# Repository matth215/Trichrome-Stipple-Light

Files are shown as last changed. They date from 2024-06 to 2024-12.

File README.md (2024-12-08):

# Trichrome-Stipple-Light
Here find my project files for the Stipple Light project I developed as a workshop with Stanford's Lab64 Makerspace. Here you can find build files, instructions, STL models, and arduino code.
The instructions for this project were made with Lab64 in mind, so if you found these instructions online somewhere, they may not be comprehensive enough to serve as "step-by-step" instuctions. Experience with laser cutting, coding, soldering, 3D printing, and general making is highly recommended. Your results may vary depending on the laser cutter you use, for example.   

## Directory of Files
- (start here) **TSL Preprocessing Guide** describes how to turn your image into a cut file for a laser cutter. This is typically the first step to transform your image!
- **TSL Assembly Guide** shows you how to put everything together, including 3D printing, cutting out your images, and assembling the electronics
- **StippleMount** STL 3D file ready for making. Print upside down!
- **StippLED Code** This is arduino code that runs on your Metromini V2. You'll see code versions 2 and 3, although version 3 is cooler.  
- **Trichrome Trotec Template** This is an SVG file for using with the Preprocessing Guide. (Trotec was the brand of the laser cutter we used)
- **Backing** Another SVG file for cutting out the acrylic lid for your stipple mount. This is designed for 1/8" clear acrylic.

## Who to contact
- Me, probably

## Disclaimer
- Because this project was developed as a student project at Stanford University, please reach out if you have any questions on intellectual property or distribution. That being said, this project is totally open source so feel free to make one yourself. 

Example

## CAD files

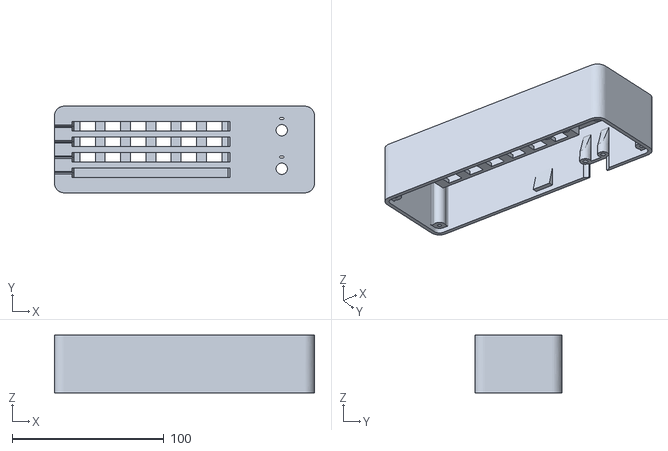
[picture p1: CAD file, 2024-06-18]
StippleMount_V4 (2).stl
171.4 x 57.2 x 38.1

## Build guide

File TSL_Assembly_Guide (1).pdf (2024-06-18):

Trichrome Stipple Light (TSL)
Assembly Guide
Matthew Hamilton for Lab64

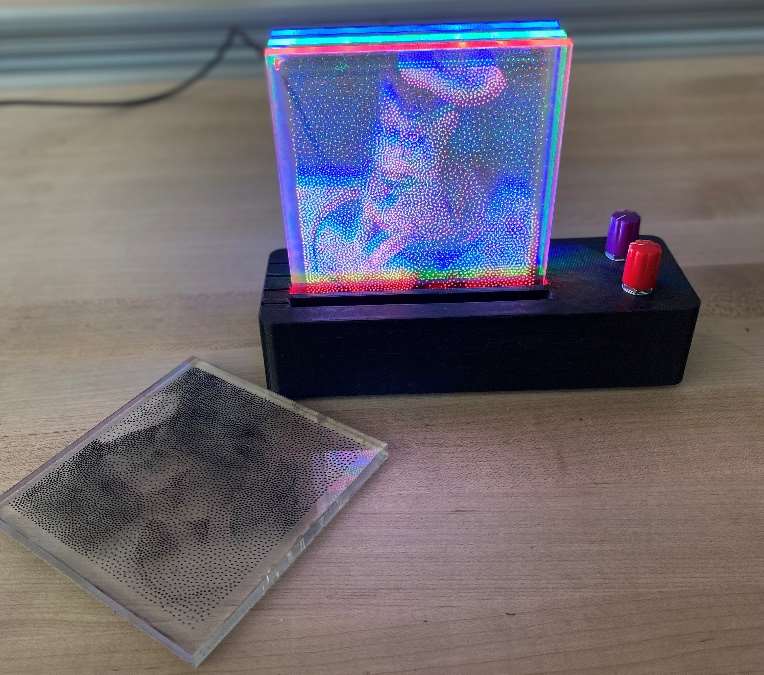
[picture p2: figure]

1

Part 0 - Orienting Yourself
The day of the workshop focuses on integration – basically putting everything together to make the final product. It’s also about sharing skills! Here you will be soldering the guts of the stipple holder, assembling the potentiometers, and putting everything into the enclosure for a clean package. All the while, your SVG files will be laser-cut out of acrylic and will be ready during the workshop.
If you’re doing this project outside of a workshop, these directions will guide you through soldering your connections, laser cutting your acrylic squares, and assembling the final product.
However, these directions don’t function as an introduction to soldering, 3D printing, or laser cutting! That’s where skill sharing comes in – if you need help along the way, reach out to a Lab64 Course Assistant to aid you in any of the techniques discussed here. You should also talk to anyone else that’s working on this project. Experience is a great teacher and they’ll be able to pass on tips and tricks not covered in this document.

Figure 1: Completed TSL prototype with Black Channel Removed
You can follow these directions sequentially, but can also choose to start at Part 1, Part 2, or Part 4. You’ll eventually hit every part on the way to completing this project.

Part 1 - Print your Stipple Holder
3D printing usually takes several hours, so it’s a good idea to start this step early. You can solder and assemble the electronics portion ahead of time while your holder is being printed. Download the Stipple Holder on the Lab64 GitLab site and import it into the Prusa Slicer.

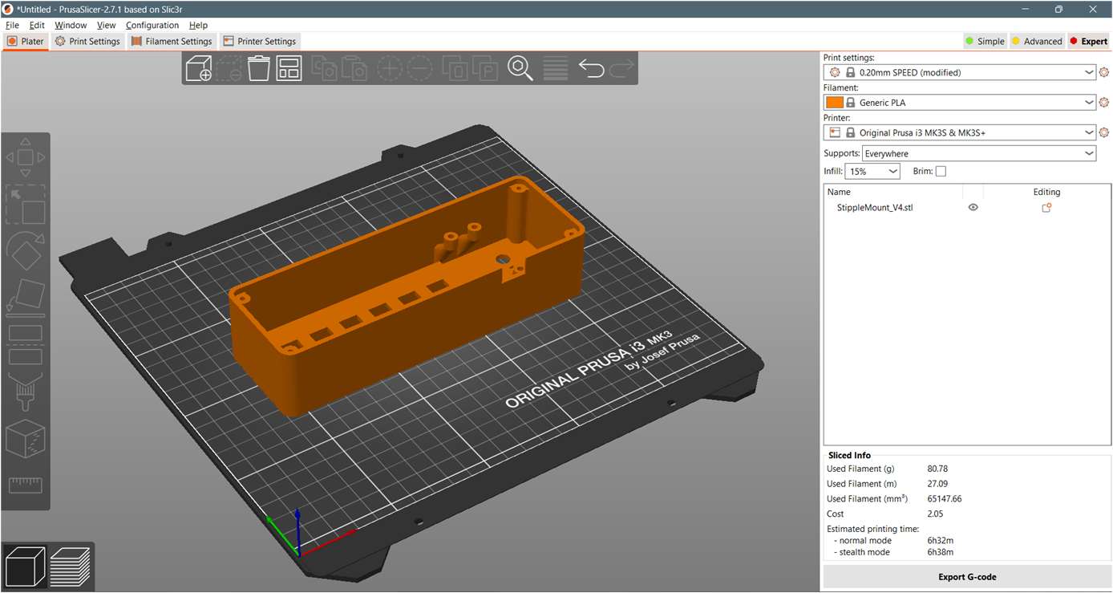
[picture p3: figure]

2

Figure 2: PrusaSlicer for the Stipple Holder
You’ll want to print it upside-down to minimize wasteful supports inside the cavity. Keep the infill to 15% with supports everywhere. Make sure “Brim” is NOT selected, or you’ll have a hard time removing supports and cleaning the edges of the box. You can use any detail and layer height that works for you. The screenshot above is just a recommendation.
Assuming your bed has no temperature issues, bed adhesion should not be a problem. In testing, we observed it takes between 8 and 11 hours to print a holder. As always, you can find the 3D model, directions, and code on our website at https://lab64.stanford.edu/.

### 1.1 Adding Heatset Inserts

You might have noticed that the underside of the Stipple Holder has 4 mounting holes in a rectangular pattern. These are sized for M2 4mm “Heatset Inserts” which couple with M2 screws and solidly secure the microcontroller to the holder. Since this is where you’ll plug and unplug your completed TSL, a mechanically sti mounting point is critical!
If you’ve never used a Heatset insert before, you’re in for a treat. They’re both an elegant way to mount components onto a 3D print (or another thermoplastic) and are immensely satisfying to use. You’ll need a hot soldering iron, your 4 brass inserts, and a pair of tweezers. With your holder upside-down on a workbench, heat up your soldering iron. Position one insert so that the wider diameter is facing up. Use your tweezers to move the insert to one of the mounting holes in your stipple holder.
Next, make sure the soldering iron tip is completely clean and free of solder. Touch the tip of the soldering iron to the brass insert to heat it up. At the same time, use your tweezers to guide the insert into the mounting holes until the brass insert reaches the bottom, and the top of the insert is flush with the sides of the mounts. CAREFULLY reposition your tweezers to the top of the insert so that they’re right next to the soldering iron tip. Remove the soldering iron tip and use the tweezers to keep the insert in place. This part is critical so that you don’t rip out the brass insert on accident!

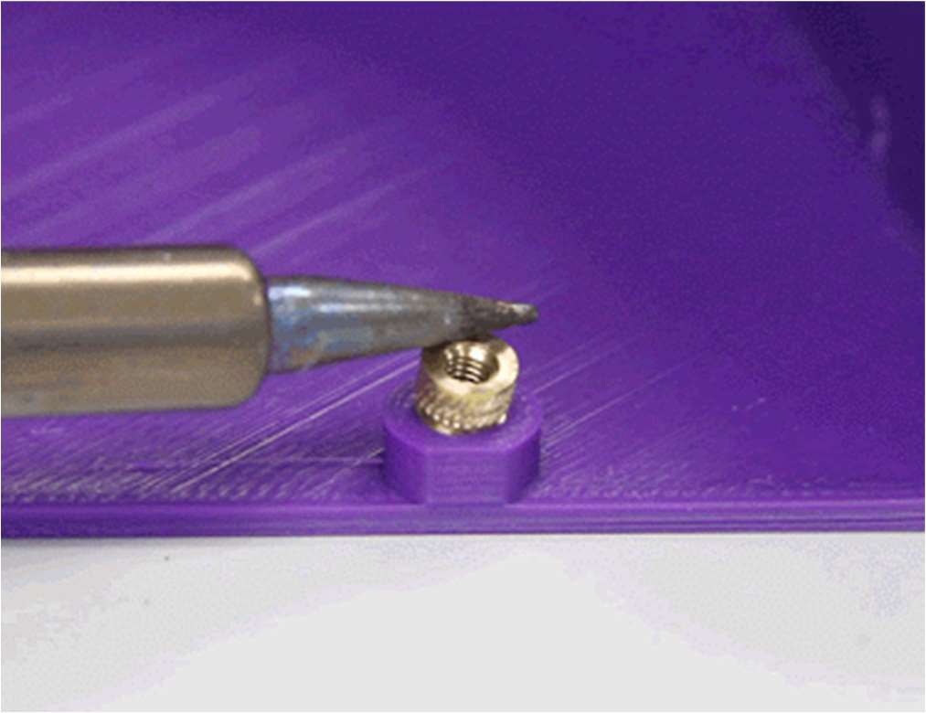
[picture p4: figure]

3

Figure 3: Animation of heatset insert process

Part 2 – Soldering
Soldering the connections for this project takes the most time out of the steps listed here. If you’re not an experienced solderer (and even if you are) you might find some diiculty soldering the wire and LED strip together. This is because the LED strips are thin and metallic making them excellent heat conductors and heatsinks. This isn’t great for soldering since we need to heat up the surface to ensure a good joint. Before starting o, here are some quick tips to think about before starting. We’ll discuss them in detail in the following directions.
- Tin your tip! Tin your pads! Tin your wires! – Solder bonds to solder easier than to metal
- Heatshrink tubing is critical for ensuring a good mechanical connection
- Use clamps and holders to make soldering wires together easier
- Don’t burn your fingers – yes, it can happen to you!
- Solder the backside of the LED strips
- Daisy-chain your connections
The wiring illustration in the last page of this document will orient you though the assembly. The TSL uses an Adafruit Metro Mini V2 as the microcontroller for this project. It uses the excellent
atmega32 chip commonly found in Arduino microcontrollers. Since it uses 5 volts, it easily powers LED strips without issue and has more than enough analog inputs for our purposes. (It also means you can expand the TSL with many more functions if you want to.)
The illustration shows the red Vdd wires and black Ground wires “daisy chained” together, except in a few spots. This means that instead of every device being wired back individually to the same ground or Vdd pin creating a clumsy ball of wire and solder, these wires jump from one device to another to complete the connections.

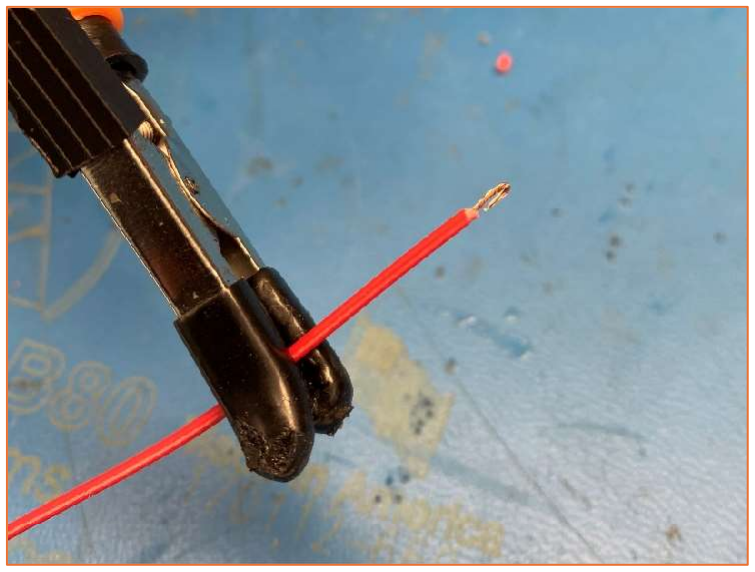
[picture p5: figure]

4

### 2.1 Tinning the Wires

Start by cutting your wires to length and stripping the tips. You’ll need enough wire to connect 2 potentiometers and 3 LED strips. You can do this all at once or as you go, but it helps to cut them ahead of time so that you can tin your wires eiciently. Consider the length of your stipple holder and give yourself some slack so the wires are not stretched when you assemble them later.

Figure 4: One wire ready for tinning, you’ll want to do multiple at a time.

Next, tin all of your wires. Tinning means using your soldering iron to apply solder to the bare wire threads without connecting them to anything. This serves 2 purposes. First, it helps keep your wire strands together. Second, it makes it MUCH easier to bond them to other components. Liquid solder bonds more easily with solder than it does to cold metal like your wire or solder pad. This is an important trick, and it will make assembly easier and less frustrating.
It’s more eicient to do this with several wires all clamped at the same time, rather than individually. Use a table vise or wire grips at your station to clasp several wire ends, but don’t let them touch each other. Apply a small amount of solder to the length of stripped wire to tin them. Then, do the same with the other ends of the wires. This may seem tedious, but it will save you time in the next steps. Don’t be tempted to hold the wires with your fingers! Copper conducts heat quickly and will easily burn you! Use a clamp or vise grip; it’s safer that way.

### 2.2 LED Strips

With the wires tinned, turn your attention to the LED Strip pads. You’ll tin these too, but this can be tricky. Clasp the LED strips in your vise grip and use a little flux to clean the copper pads. Make sure you tin the back side of the pads! Otherwise, the LED Strips won’t lay flat into the stipple mounting holes. All wires going in and out of the LED strips should attach to the back side of the strip, including your signal wires. It’s super important that these connections are snug with the pad and no extra length of wire is exposed. This is a common point of failure – make sure there’s no chance

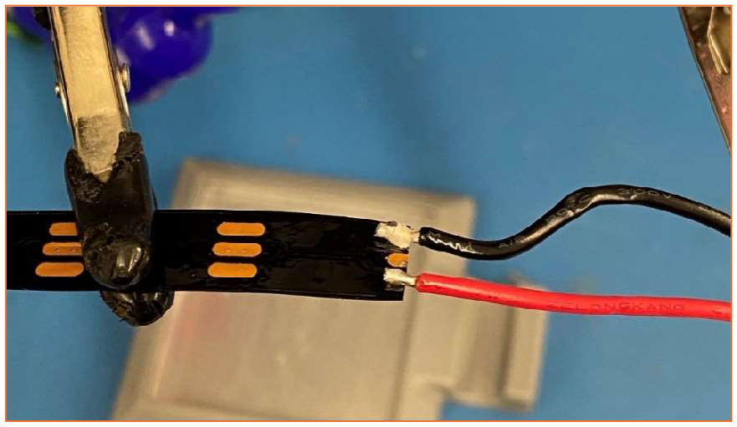
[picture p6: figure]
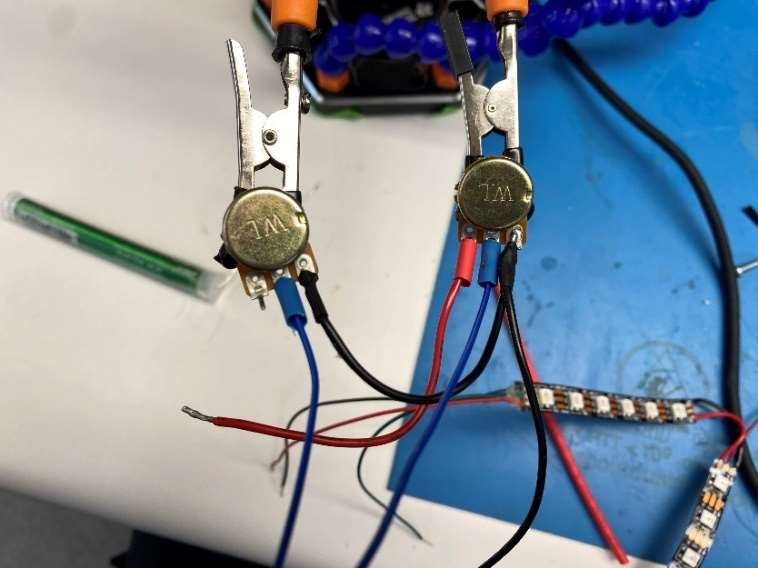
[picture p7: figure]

5

that any of the wires can touch each other! You’ll stabilize this connection later during assembly with hot glue.

Figure 5: Power wires soldered to the LED strips. Note that these are on the back, and the wires insulation is snug with the solder pad

### 2.3 Soldering the Potentiometers

Now you can solder the wires to the potentiometers. Tinning the potentiometer leads can help here too. During the workshop, we noticed that some of the potentiometers are either defective or break during soldering. Try not to apply too much heat to the pot leads when soldering them to reduce this risk. Reference the wiring diagram on the last page and take care to slip on heat shrink tubing on your wires before you solder if you’re soldering multiple wires. Forgetting to put on heat shrink tubing after you’ve made your solder joint is a rite of passage. Since you are daisy chaining the connections, there will be a few points where you’ll slip heatshrink over 2 wires instead of just one!

Figure 6: Wires going to the potentiometers. The “signal” wires are blue.

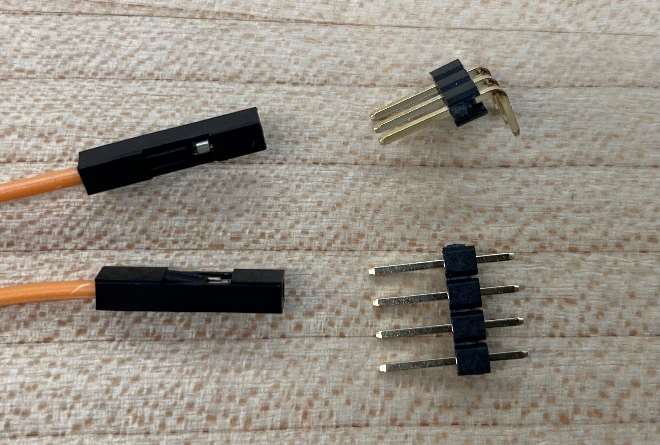
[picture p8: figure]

6

### 2.4 Header Pins

Last but not least, you’ll need to add female header pin connectors to the ends of your signal wires going to the microcontroller. These will connect to the male header pins soldered onto the microcontroller and simplify assembly at the end. (On the wiring diagram, these are the little black rectangles pointing towards the microcontroller.) Secure this splice with a bit of heatshrink.

Figure 7: Female wire header connectors (left) with male header pins in straight and angled variety (right)
Turning to your micro controller, solder the male header pins to your board at the appropriate spots. The angled pins will connect to the LED signal outputs, and the straight ones will connect to power and analog inputs. This is an important detail for assembly later. Just solder the pins you need; don’t use the whole strip or the micro won’t fit into the stipple holder!

### 2.5 Final Steps and Checks

As you work through the solder connections, pay careful attention to the connections, and take your time. When you’re finished, take a look at all of your solder joints to make sure they’re mechanically stable. Could you add heat shrink anywhere? Is there any chance your wires could cross and short out? Are you sure you wired the ground pins to the ground wire, and the power wire to the power pins? Did you connect the LED strip signal wires to the Din side, and are your Dout pads unconnected? Have you had a snack? These soldering steps can take a good amount of time so keep your blood sugar up and don’t get frustrated. If you’re satisfied with your job, congratulations! This is a challenging soldering job that takes a good amount of skill. The next step is testing it with your microcontroller.

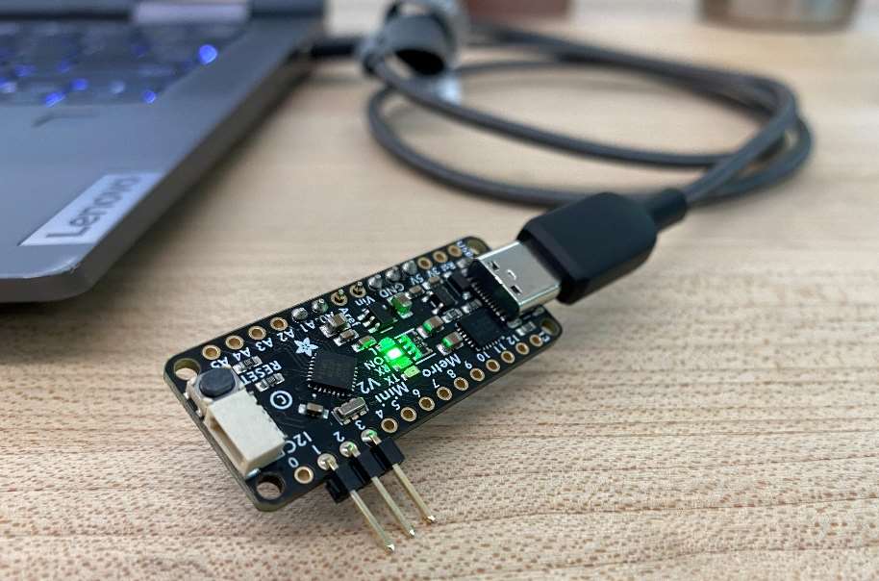
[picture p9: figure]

7

Part 3 - Testing your Circuit and Microcontroller
At this point, your LED strips, potentiometers, and microcontrollers should all be connected together but unattached to the stipple holder. This is a good chance to make sure the guts of this project work right so you can fix issues now. Grab your laptop, microcontroller, and a USB-C connector. You’ll also need the following software:
- Adafruit MCU Drivers, to get the configuration of your MetroMini V2
- Arduino IDE, the development environment for Arduino-based microcontrollers.
- USB to Serial Drivers for connecting to your microcontroller on Windows (if you’re using mac, refer to Adafruit’s guide here
- StippLED Code from Lab64’s Gitlab.

The software above is everything you need for testing, connecting to your microcontroller, and uploading the TSL code. If you have issues with this step, follow the manufacturer's instructions on their website at learn.adafruit.com. Start by downloading and installing all the software listed above.

### 3.1 Connecting to the MCU

With the Arduino IDE page open, connect your computer to the microcontroller using a USB-C cable. Remember, don’t connect any of the electronics in the previous step to your board!

Figure 8: MetroMini V2 connected to a PC. Note there's no other electronic attached to this yet!
If you haven’t already, add the MetroMini v2 to your board manager in the Arduino IDE settings. Reference the screenshot below to connect to your board, but keep in mind that your serial port number will be dierent. It’s typically a number higher than 6. For me, it was COM23 Serial Port (USB). Notably, the serial port number changes every time you reconnect your metro so you may have set the com port again if you disconnect the microcontroller. With your board connected, you can now download the StippLED code and copy it into your board’s .ino file. You’ll also need to install the “fastLED” library from the IDE’s Library Manager, as well as Arduino AVR Boards from the

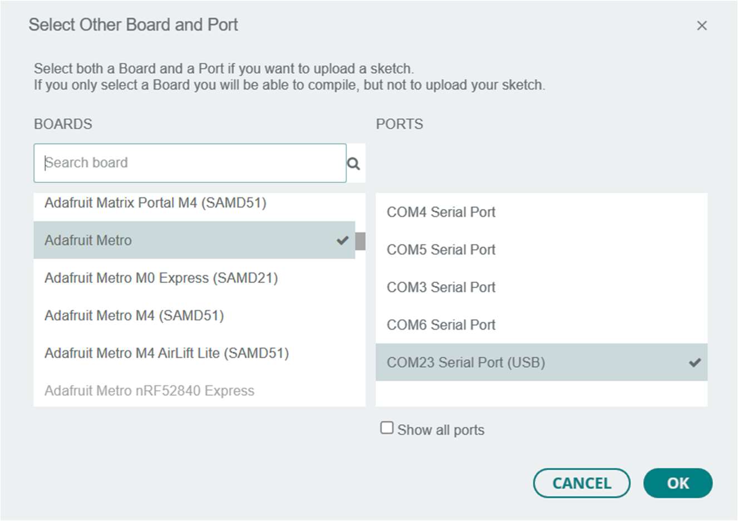
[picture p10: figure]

8

Board Manager. Otherwise, you’ll get an exit error message from the serial terminal whenever you try to upload.

Figure 9: Arduino IDE Boards Manager (under Tools > Board > Boards Manager)
It’s important not to look at the code for too long – it’s probably not up to any CS Major’s standards (from Stanford or anywhere else). This is, however, the best code you can expect from an EE Major who learned Arduino in a few weeks. If you’re comfortable with Arduino this project is an excellent opportunity to develop your own firmware with custom LED animations (once you’ve assembled everything). You’re encouraged to add your own code and share it with everyone else, so that they too can judge your code :)
Now, upload the code using the arrow button. If your code uploaded successfully without error, then your IDE is configured correctly. If not, you might have issues with the board manager, libraries, serial drivers, or MCU drivers. Go back and check these before proceeding to the next step.

### 3.2 Testing the Electronics

Bring over your mess of LED strips and wires to your microcontroller. Unplug your microcontroller from your computer so that it’s completely powered o. While looking at the schematic diagram, connect the female header sockets to the male header pins on your microcontroller. Take special care in ensuring that you’re not shorting any connections accidently. Then reconnect the microcontroller to your computer. The micro should immediately begin illuminating the LEDs depending on the position of the potentiometers. Turn both POTs and see if it’s working as expected. One POT will shift through color schemes, and the other will vary the intensity of the lights.

9

### 3.3 Troubleshooting

If your lights are not working as expected but you uploaded code in the last step, the issue is with your circuit. A short in your wiring can cause issues compiling code to your microcontroller! This is why we tried uploading the code to the micro before testing the circuitry. Here are common issues we found during the workshop.

### 1. LED strips are flashing and/or sensitive to small adjustments: Check the wiring at the

LED strip pads and make sure there are no shorts. Are your wires soldered closely to the pads like in figure 4?
2. Some strips are not illuminating: Check that your signal wires are connected to the Dn (or Din) pads, and the Do (Dout) pads are not connected.

### 3. Turning the POTs does nothing: You might have a bad potentiometer causing an open or

short condition inside the canister. Test the resistance value using a multimeter. Also check that the signals inputs are connected to AD1 and AD2.
4. Trying to upload the code fails and nothing works: You likely have a short between 5v and ground pins somewhere in your wiring resulting in insuicient power to run your microcontroller. Trace these connections and find the fault.

### 5. Code uploaded successfully, but nothing works: Check the power and ground

connections and ensure they are soldered properly. It’s also possible that your POT inputs and signal outputs are shorted to ground or 5v preventing a signal from reaching your LED strips.
Once you’ve worked out all of the bugs in your circuit and it works as expected, you can move on to another part.

Part 4 – Acrylic Laser Cutting and Finishes
You’ll need laser cutter training to do this part alone or ask a CA for help. We used the following settings to cut the acrylic from the templates.
Engraving: Power: 80, Speed: 30, dpi: 333 to 500
Cutting: Power 70, Speed: 0.55, passes: 2
Cutting 4 acrylic squares at the same time can take around 30 minutes as the laser head rasters over the sheet. After they’re done, you can start putting the finishing touches on the 4 color channels. They’ll still be dusty from the cut, so the first step is to wash them vigorously in the sink.

### 4.1 Preparing and Painting

Take them over to the reflow room and use the lab sink to wash out the acrylic dust. The dust tends to get stuck in the stipple dots, so wash them until the acrylic appears clear under the water. You can also remove the plastic film from the blanks at this point. Dry them o using a microfiber towel. Acrylic can scratch easily, so be careful and don’t use any hard tools! If you’re a perfectionist, you can look at the stipples under the microscope in our lab.

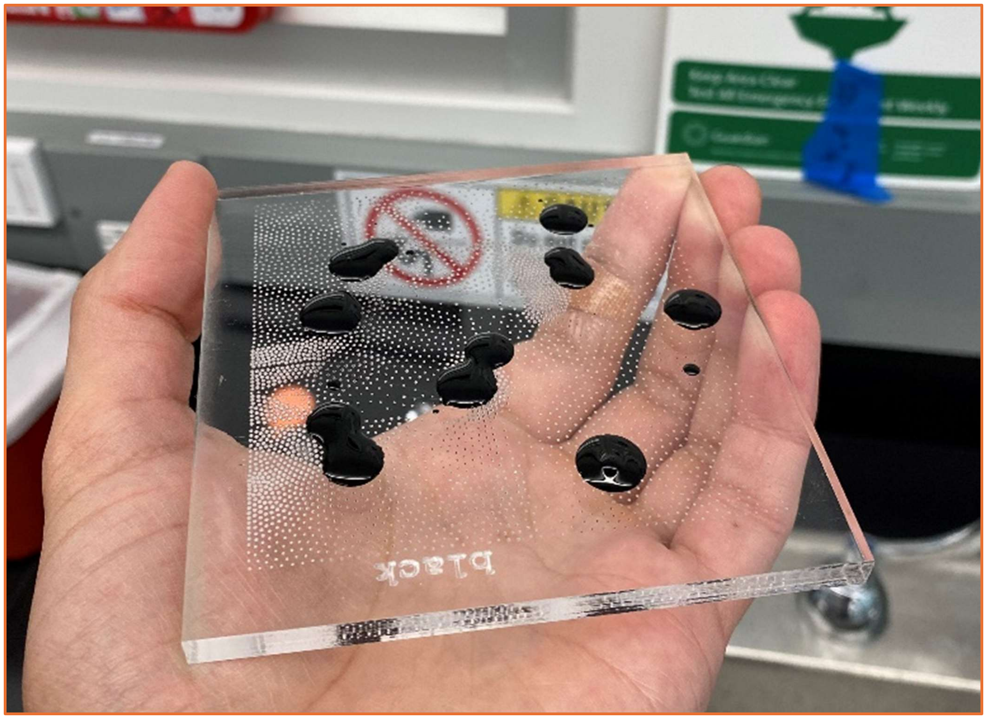
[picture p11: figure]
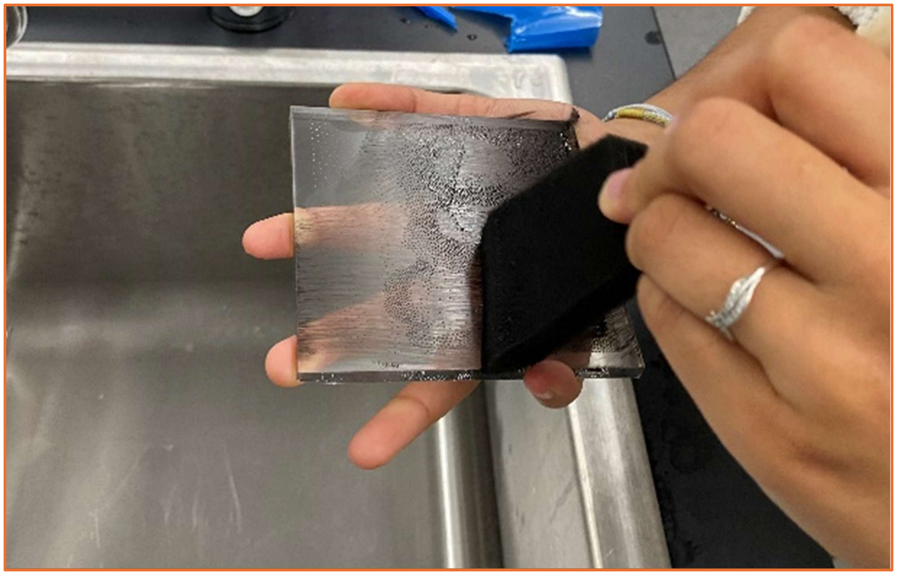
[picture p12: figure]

10

Now find your black acrylic square. If you labeled it, this should be easy. If not, then you’ll notice that one of the images has a notably dierent pattern than the color channels and you can hopefully find it this way. In this step, we’re going to add pigment to the stipples so that they blend and add darkness in the resulting image. This isn’t possible with RGB light alone, after all. Remember – we’re only doing this with the black channel! Not the other color channels!
Over the sink (please), use the tube of black acrylic paint and add several drops to the stippled surface of your plate like this:

Figure 10: Black paint on the black channel
Then using the paint brushes, dab the black paint into all the little stipples. Do this several times to really get the paint in there. It can help to use a paper towel and circular movements to better put the paint into the stipples.

Figure 11: Brushing the black paint on
With enough work, you’ll see the black paint covering the entire square. Then, use a damp paper towel to wipe the excess paint o and clean up the square. Take a look at how the acrylic paint has filled the dots. If you’re not satisfied, repeat this process until you are.

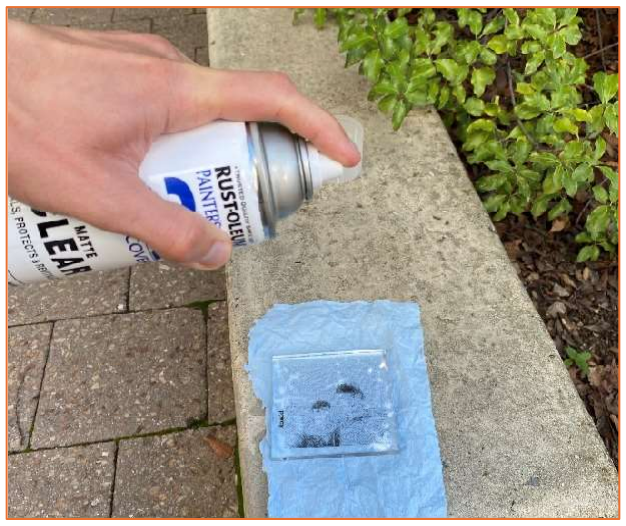
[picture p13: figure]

11

### 4.1 For Overachievers

If you really want to make sure all the stipples are filled you can take the extra step of evacuating the air in the acrylic paint. You can use the small vacuum chamber along with the vacuum pump to pull all of the air out of the paint.
Apply a thick coat of paint on the stipples, then place it in a plastic container that will fit into the vacuum chamber. Place both at the bottom of the chamber then place the lid on top being sure to center it exactly. Pull a vacuum in the chamber until the pressure has stabalized. You’ll see all of the air leave the paint and dry out a little bit. Leave it for about 1 minute, then return pressure to the vessel. Take out the acrylic and wipe o the surface. This is the best way to ensure the paint has entered every single stipple.

### 4.2 Optional Step:

We’re not sure how good this eect looks, but you can add a coat of matte clear coat on the black mask to “enhance the blending eect”. It makes the image look better upclose (maybe), but isn’t necessary to get the full eect. This is an asthetic choice.

Figure 12: Spray lightly from about 1 foot away to apply an even coat

Part 5 - Putting It All Together
You have your clean acrylic squares and they’re ready to go. You’ve tested your spaghetti mess of wires and LED strips with your microcontroller and it all works great. Your Stipple Holder is clean and the heatset inserts have been heated, set, and insterted. It’s time to put it all together.

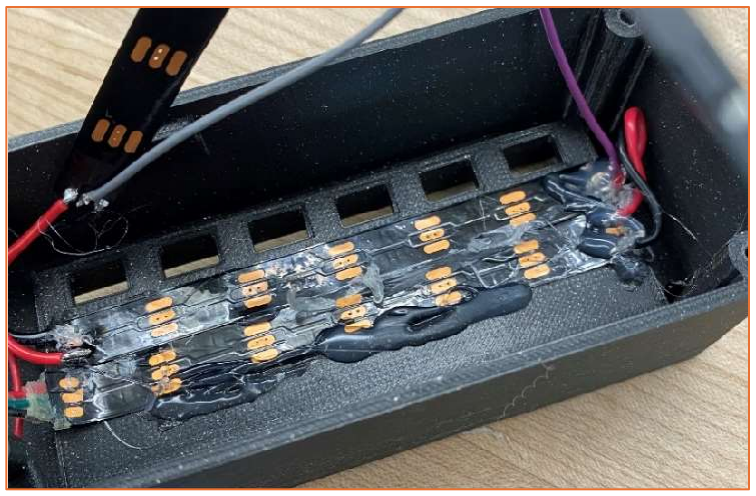
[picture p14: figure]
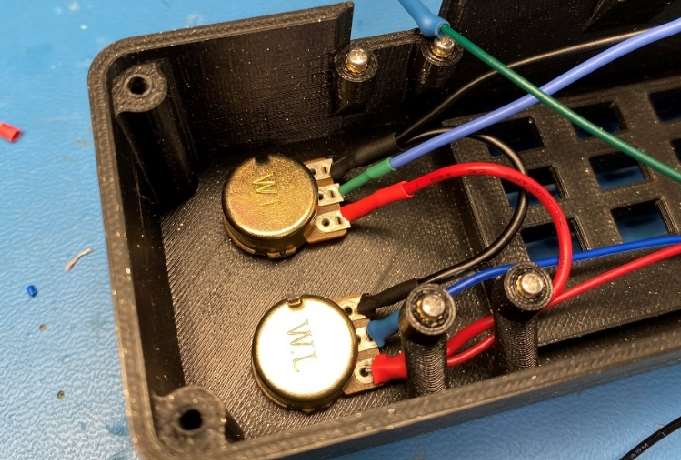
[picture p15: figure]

12

### 5.1 Hot glue for the LED Strips

Begin by carefully test fitting the led strips into the holder. You’ll notice that there’s a gap for every led strip. Here, you’ll use a little hot glue along the edges and “bridges” of the slots to hold your LED strips in place. This can be messy but it works well.

Figure 13: 2 out of 3 hot-glued LED strips. Glue on the solder pads also help prevent shorts during assembly
Next insert your potentiometers. These don’t need hot glue and instead secure with a washer and nut on the top face. When that’s done, add the knobs of your choice to the two pot shafts. These typically secure with pressure alone, or with a small hexscrew on the side of the knob which you’ll adjust with a allen wrench (hex key).

Figure 14: Pots inserted into the stipple holder

### 5.2 Microcontroller and connections

Next, secure your microcontroller to the 4 inserts you secured in part 1 with 4 small 2M screws. Because this microcontroller is also the main plug for your stipple holder, the heat set inserts provide a mechanically stable and secure point for attaching and detaching the USB-C cable for power. With this installed you can now attach the female header pins to their respective pins on the

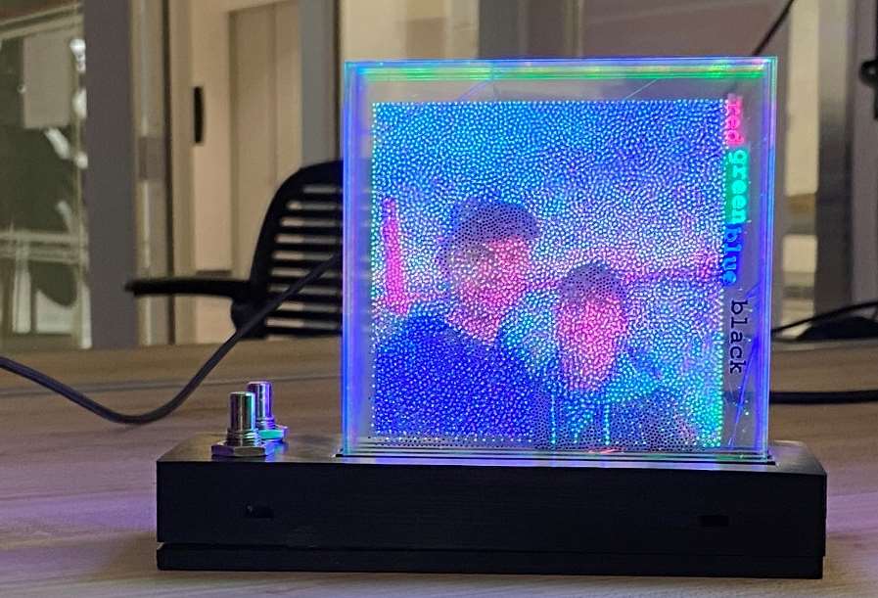
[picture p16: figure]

13

microcontroller to complete your circuit. If you soldered the male header pins correctly, you’ll notice that the angled pins point conveniently towards the LED strips making this connection easy. At this point you’re almost done! Use a little extra hot glue (if you want) to secure the loose wires to the stipple holder.

### 5.3 Securing the Acrylic Backing

Now with all of your wires connected and secure you can close it up using the provided acrylic backing. If you can’t find one of these in the workshop supplies, you can cut one yourself using the SVG file on our Gitlab page. The four holes of the backing secure easily to the stipple holder using 4 #6-19 screws 5/8" in length (similar to M3.5 screws). If you can’t find these, you can use any self-threading screws sutable for plastic. All this means is that these particular screws press into the surrounding plastic along the shaft to create threads. Speaking of which, be very careful screwing in these screws for the first time! Place your stipple holder upside down on a steady surface and use a good amount of pressure to put these in. Try this without the acrylic back`ing to make the threads first, then rescrew them with the backing in place.
Finally, stick 4 small rubber pads to the backing to give your stipple holder some legs to stand proudly on your coee table, luxury Stanford dorm room furniture, night stand, or any other surface near an outlet. When you add your 4 color channels and plug it in, you should see the final result!

Figure 15: Final project using the example image in this document. The Stipple Holder is from an earlier revision. Knobs are not installed.
Congratulations on completing this project. The TSL was designed to give makers a more challenging project that would use a wide range of skills. Be sure to pass on what you learned to another maker and recommend this project to someone else!

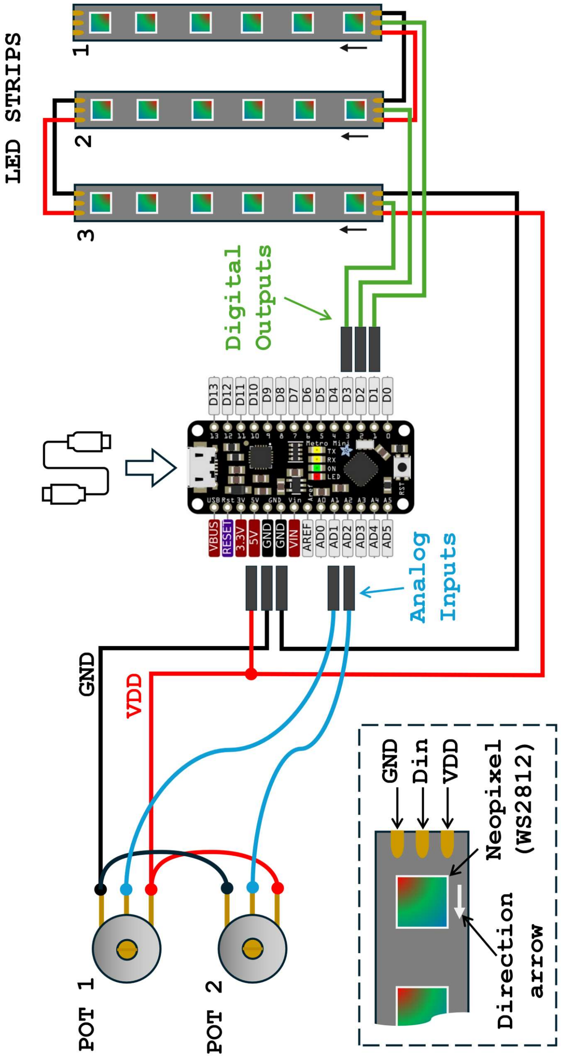
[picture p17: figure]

14

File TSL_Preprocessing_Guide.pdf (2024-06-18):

Trichrome Stipple Light
Directions for Image pre-processing Matthew Hamilton for Lab64

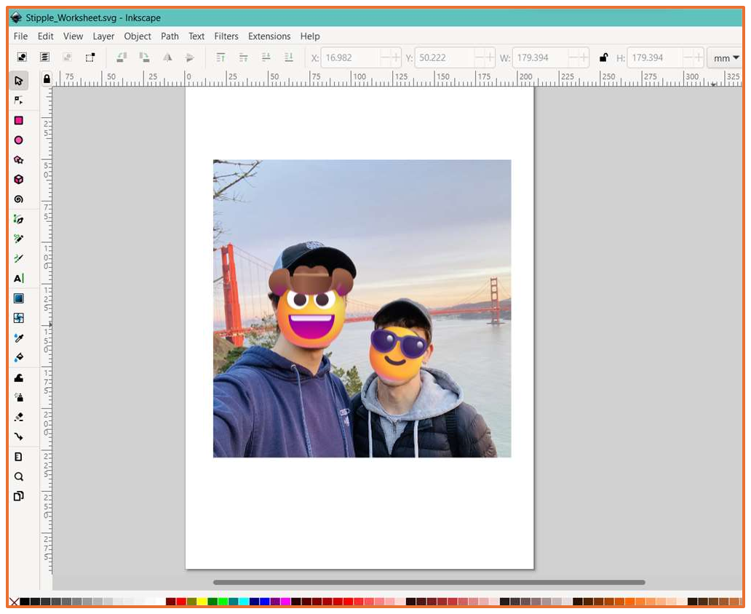
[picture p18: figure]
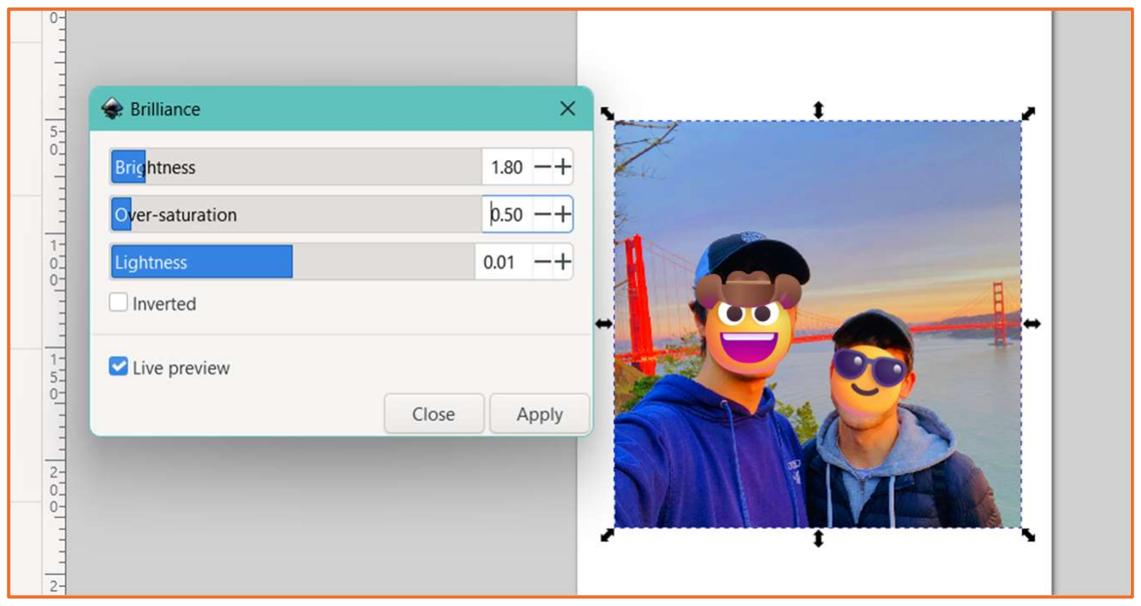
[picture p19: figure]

1

Getting Started
There are three parts to this pre-processing, and we’ll go from Inkscape, to StippleGen, then back to Inkscape. You can use any image you like for this project: Dogs, cats, family, friends, landscapes, significant others, or anything else! However, photos that work best for this project are vibrant with good contrast and without too much detail. Be sure to crop your picture to a square aspect ratio before beginning. Start by opening a new Inkscape Document, then import your square image onto the document.

Before we start sampling the document in StippleGen, we need to make a few edits to the picture. The end result will be pretty colorful, but more subtle colors tend to be washed out. It helps to brighten the tones and saturation. Thankfully this is easy in Inkscape! You can apply a variety of eects to adjust the color of your image.
Select your image, then in the menu bar select Filters > Color > Brillance.

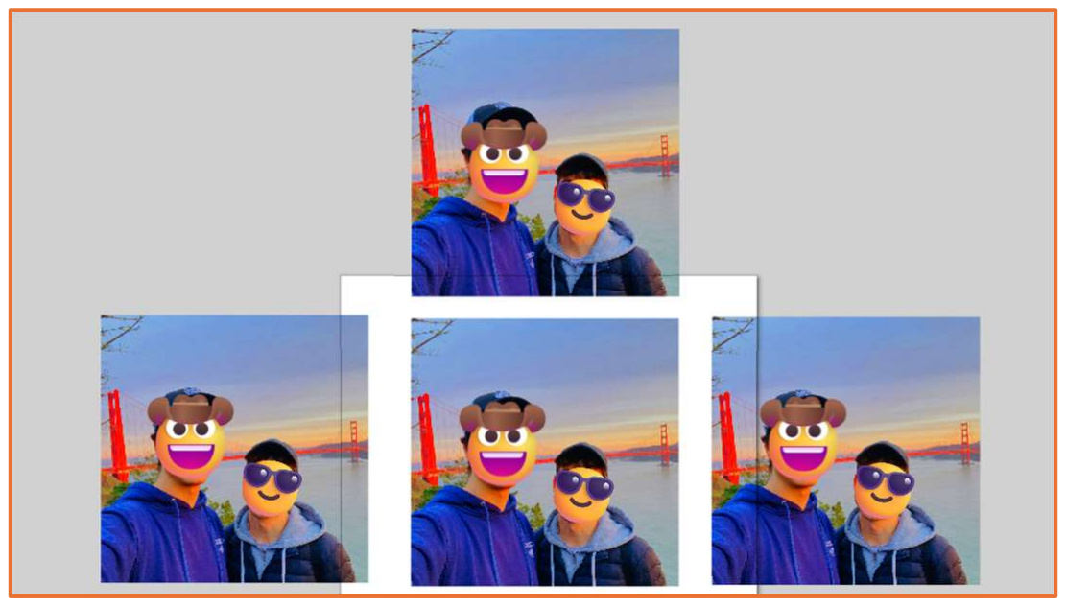
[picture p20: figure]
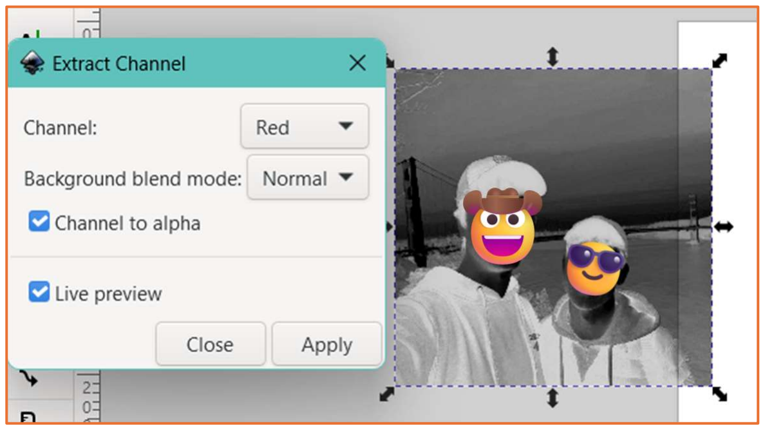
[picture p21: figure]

2

Select “Live Preview” and adjust the brightness, Over-saturation, and lightness if needed. You want your image to be pretty over saturated, but not excessively bright. Contrast is the key here! Think dark lines, and colorful tones. When you’re happy with your image, move on to the next step.

Splitting the Channels into RGB
Next, copy your image three times to create 4 images in total on the same sheet like in the image below.

The bottom three images will become our color channels red, green, and blue. Select the first
image, then select Filters > Colors… > Extract Channel | The dialog box that opens lets you select
several channels. Start with Red and be sure to select “Channel to alpha”. This is necessary for the next step!

Take a look at your spooky red channel image. Does it make sense to you? Red hues will show up dark, while colors with very little red should show up white. For example, the blue sweater shows up white because it has almost no red in it. Bright colors like a cloudy sky or white background will have a mix of all the colors. The darker the color, the more the stipple dots will cluster around that area in the next step (which is, by the way, the key working principle of this project!)
Repeat this for the other two channels, until you have 3 grayscale images of your color channels. It helps to do this in order from red to green to blue, so you don’t mix them up! Your end result should look like this:

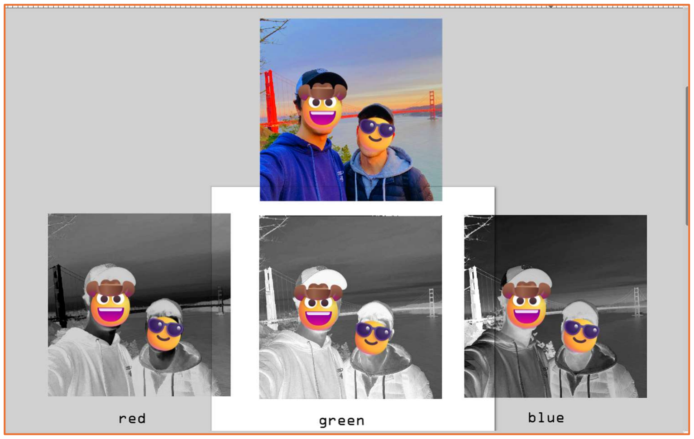
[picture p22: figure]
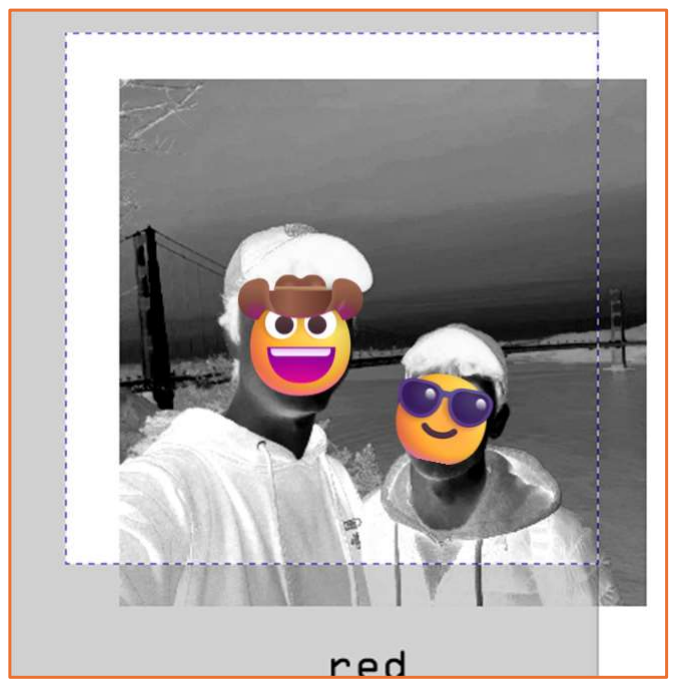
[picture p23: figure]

3

The color channels come out as transparent. This introduces errors when trying to export as a JPEG in the next step in which everything is super dark. To fix this, make 3 white squares with the same dimensions as your channel images. (To make this easy, adjust the dimensions of your images to a 7in x 7in square. This tool bar is typically at the top.)

Place the white squares directly underneath your images. Be sure that they are exactly the same size as your image (7” x 7”)! Adjust the layer order by going to the layers tab and putting the white squares behind your images so this works correctly. Use the align and distribute tool to make this easier. Once you have both, select them and click “group”. Again, all images must have the same dimensions!

(The image above shows both the white square and the color channel for this explanation but move it so that it’s directly under the color channel). Do this for the 3 color channel images and then move on to exporting.

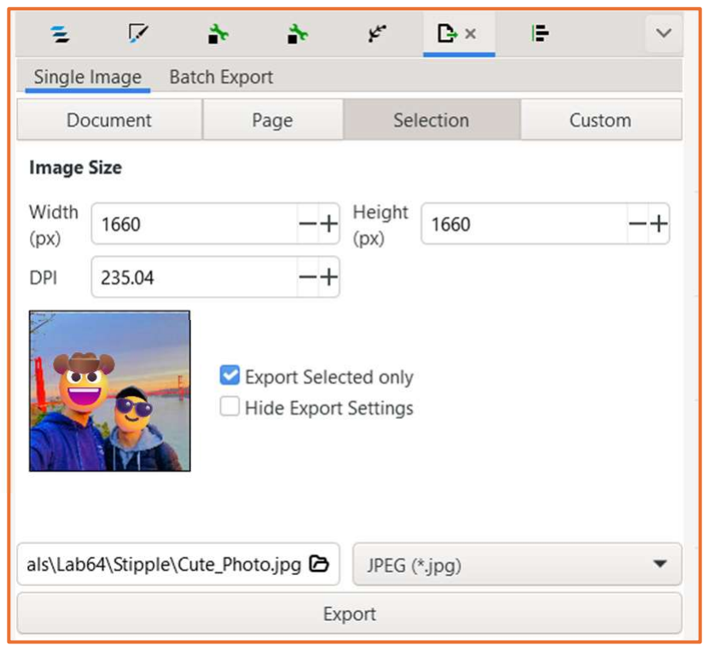
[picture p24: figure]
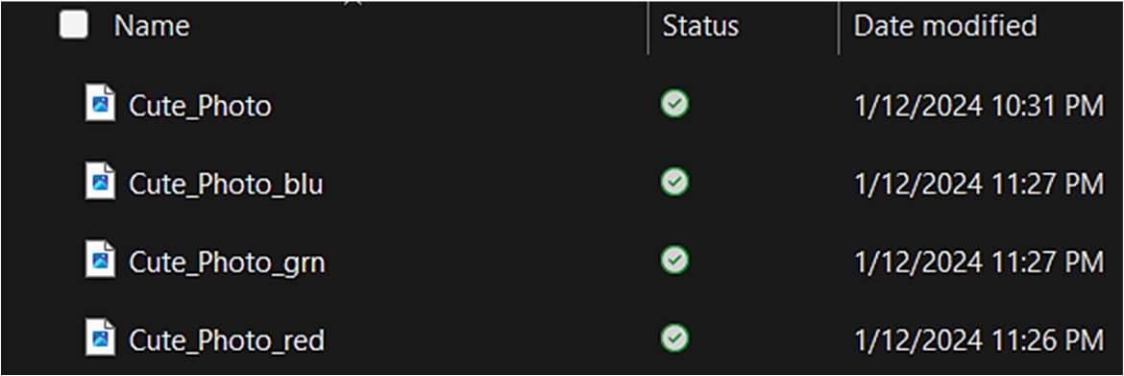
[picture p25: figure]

4

Exporting to JPEG
You’ll need to export all 4 images (full color, and 3 channels) into a format StippleGen can use. When you manufacture the acrylic plates, you’ll have red, green, blue, and black channels. The black one is necessary because you can’t create a dark spot with clear acrylic and light.
In the right panel, select | and the “Selection” tab. Drag a box around both your image and
the white square underneath to select them both. Reduce the dimensions to 1660 px by 1660 px, and JPEG as the output format. Take note of the output location. (You can change it if you like – it helps to keep all your files in the same folder.) Click export.

You might get a “Low Quality” warning. This is because Inkscape is primarily a vector graphics editor which is (in principle) a lossless image format that uses equations to save images. JPEG ruins all of this but that’s okay for our purpose!
Do this for the rest of your images but add a label to the file name to keep track of the channels. At the end, your files should look like this:

StippleGen2
This is the step where most of the magic happens. If you haven’t downloaded and installed StippleGen2 yet, do so from the Evil Mad Scientist GitHub here: https://github.com/evil-mad/stipplegen/releases/tag/v2.31 This is light-weight software that will do the critical image processing for us. Inkscape doesn’t have a similar tool (yet). It’ll also rev up your CPU so this is a good time to plug in your computer!

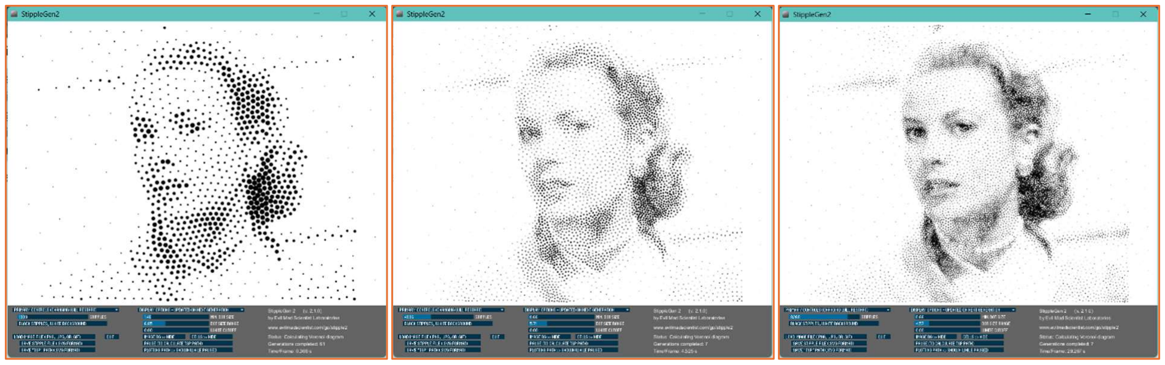
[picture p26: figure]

5

We are encoding color information into patterns of dots. Pretty wild right? Because of that, it's super important that we maintain the color information between the steps in this part. So whatever options you decide on in StippleGen2, make sure it's consistent between the color channels. Open Stipple Gen. You’ll notice it begins to sample an image of the actress Grace Kelly. Watch it for a bit so you get an understanding of what this program is doing. In each generation, the image becomes clearer.
We’ll start with your full color image. StippleGen 2 will process this as a grayscale image which we’ll
use as our black channel. Select | and grab your file. We’ll play around with
the basic settings to optimize your stipple image. But to summarize ahead of time, we want to keep these few points in mind:
- Stipples should be as big as possible without touching each other or clumping up.
- Increasing the stipple count will also increase how long the next generation takes.
- The bigger the dot, the bigger the illumination.
- More stipples = more detail.
- White cuto helps remove errant stipples.
The end of this section includes the recommended settings but read ahead to get a description of each one. Let’s start with Stipple count.
Stipple Count
The stipple slider simply increases the number of dots in your image. The more dots you have, the more detailed your image will become, but the longer it’ll take to generate a full image. (It can take several minutes to make a single generation if you push this past 8000!). Take a look at the example below using the default image:

The more stipples you have, the more “literal” your image will be. The fewer you have, the more “impressionist” your image will be. However, keep in mind that you’ll have 4 total images making up your stack. You’ll also need enough room between the stipple for the other 3 colors to shine through. If you choose 4000 dots, your final stipple light will be made up of 16,000 dots!

1000 stipples (left), 4000 stipples (middle), and 8000 stipples (right) with adjusted dot size to prevent clumping.

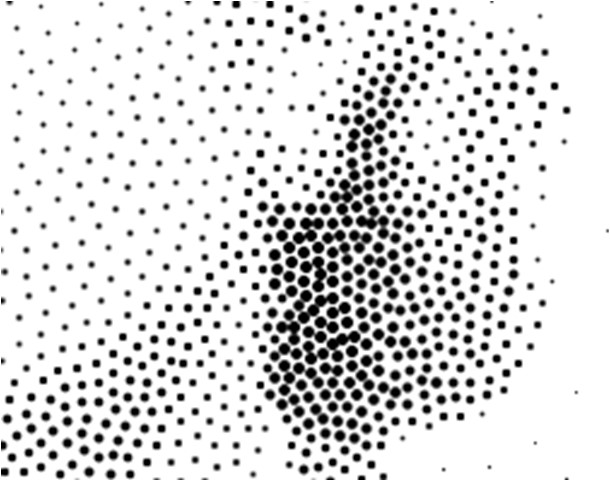
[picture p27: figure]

6

Stipple Dot Size
Min Dot Size determines the minimum size of the smallest dot, while Dot Size Range changes the variance between the smallest dot and largest dot. The key to good dot illumination lies in the depth and surface area of each dot. Since the acrylic is illuminated on the side, the dots obstruct the bouncing light and reorient them perpendicular to the acrylic sheet, collectively forming an image. Clumping the dots removes how much illumination each dot will emit. Conversely, dots that are too small will not illuminate enough and you’ll get inadequate light shining through. Here’s an example:

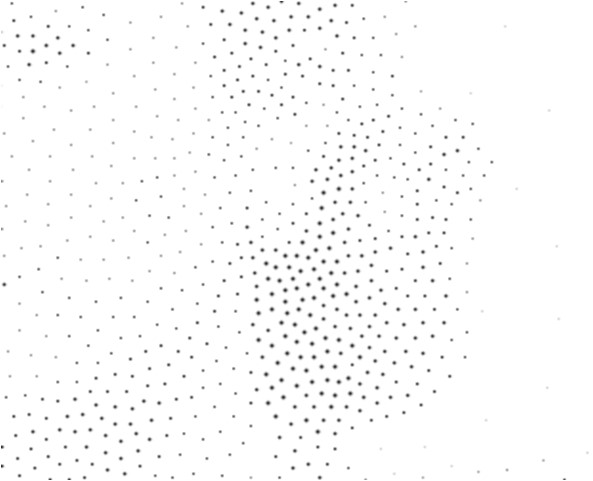
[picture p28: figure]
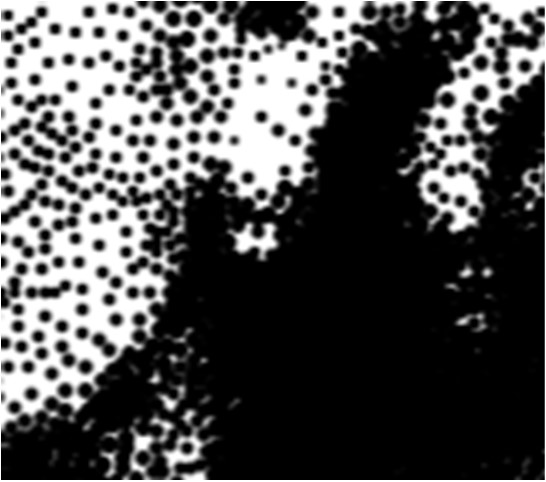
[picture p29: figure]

The goal is to get the largest dots you can without them totally overlapping.
White Cuto
This setting is straight-forward. White cuto removes the dots where very little to no color information exists. You may notice tiny white dots at the left and right of your square image in stipple gen. Increasing white cuto removed these and in eect, removes “noise” from the image. It’ll also leave you with a nice square-shaped collection of dots for the next part. Increase this value to between 0.05 and 0.1.
Summary
You’ll only need to play around with settings once before repeating this process with your color channel images. Keep in mind that the detail won’t be great (or even recognizable) for any one image, but between all 4 you’ll get a good reconstruction of it. Additionally, there’s no way to enter an exact number into the sliders but try to get close. Here are the settings we recommend:
- Stipples: 3000 to 6000
- White Cuto: 0.05 to 0.1
- Min Dot Size: 0.25 to 0.8
- Dot Size Range: 3.5 or less
- Generations: 15 to 20 (or until no dierence)
These don’t have to be exact, and you should use whatever settings work best with your image. Afterall, each image will have dierent needs!
When you're satisfied with the image, select “Pause (To calculate TSP path)” and then “Save Stipple File”. Save your first Stipple file as the black channel and add .svg to the file name.

Three dierent Min Dot Size settings. Left is set to 0 – you can’t see anything! Right is set 8 – way too much clumping. The middle image is good enough! :)

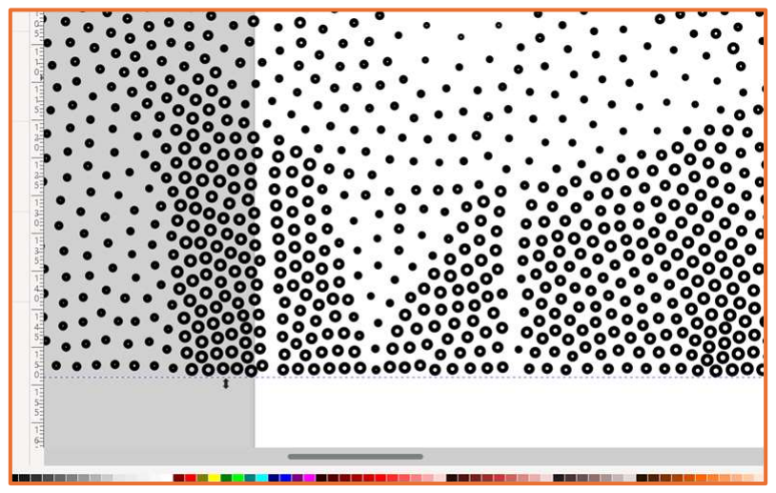
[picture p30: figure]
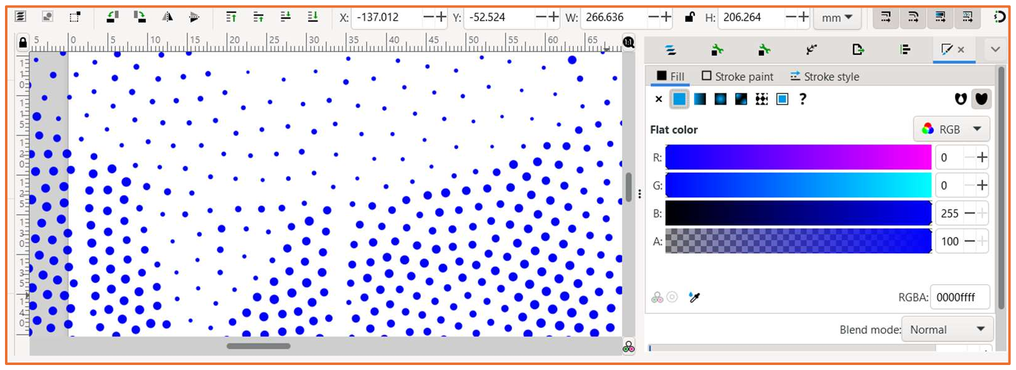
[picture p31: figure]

7

You just made your first stipple image! Now click “pause” again and load your next channel and repeat this process until you have all of your channels saved as “.svg” files. When you’re done, move on to the next step.

Making The Trotec File
All of your hard work will need to be assembled into a master SVG file which we’ll use to engrave the acrylic blanks. For this open Inkscape again and create a new document with a canvas size of 20” x 5”. You can also use the “Trichrome Trotec Template” to make the last step a little easier. IMPORTANT NOTE: Save often! Depending on your system, Inkscape might not be able to handle a large number of objects. Performing too many operations too quickly might crash the program. Do these next steps slowly and let Inkscape render everything fully.
Import your first stipple by selecting File > Import… and navigate to your folder. Use the default settings for import. Your stipple drawing will be around 4000 tiny dots each with their own outline and fill.

As you know in our laser cutting training, the Trotec uses solid-filled shapes with no outlines for engraving, which is the operation we’ll use. Adjust the fill and line settings so your channel is made up of solid dots without outlines.

We’ll also set the final dimensions of the image. Our acrylic blanks are 4” x 4” so your image should be no more than 3.3 “ x 3.3” to make room for mounting. Select your stipple and with the aspect ratio locked, adjust the height to 3.3” (or lower, up to you). You may notice that your stipple isn’t a

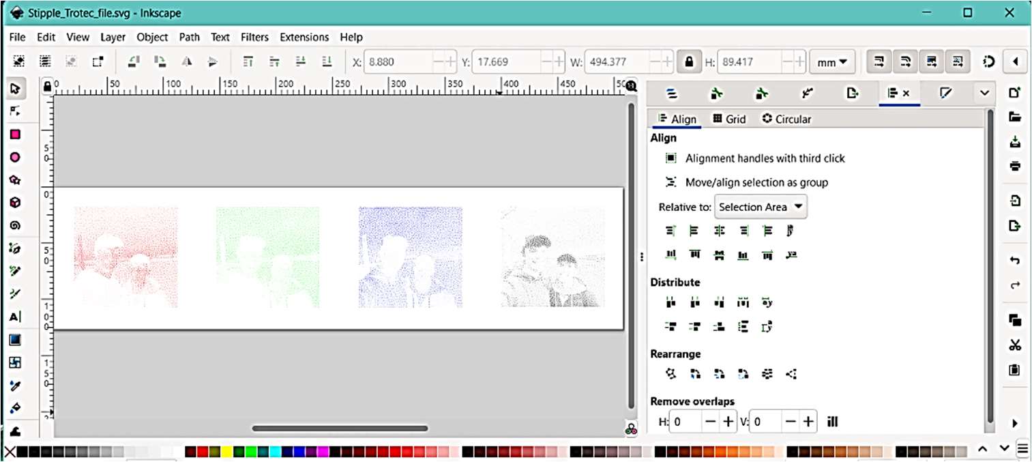
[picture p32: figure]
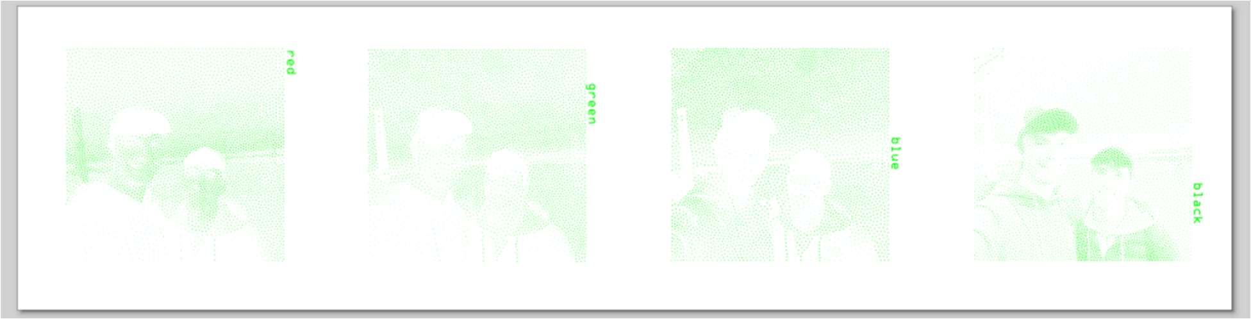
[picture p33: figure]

8

square since the program can output a rectangular image regardless of the input dimensions. The majority of your stipple should be square. You might have errant dots to the left and right if you didn’t use white cuto in the last step, but these can be safely ignored.
Next, repeat this process with your other 3 stipples. Align them side-by-side on your canvas. We’ll change the stipples all to the same color at the end, but it helps to color the stipples so you can keep track of them.
Use Inkscape’s alignment tools (Object > Align and Distribute…) to make your 4 stipples on the same horizontal line. Distribute them horizontally as well. Here’s what it should look like at this point:

Here you can add text to label the color channels, so you know which is which after engraving them. (Or don’t do that and figure it out later – could be fun.) You can also add your name, designs, or text. The stipples act a little like randomly-spaced pixels. Any colors you choose will be blended in the final result.
Now, let’s make everything the same color. Everything here will be engraved so using a single color is necessary.

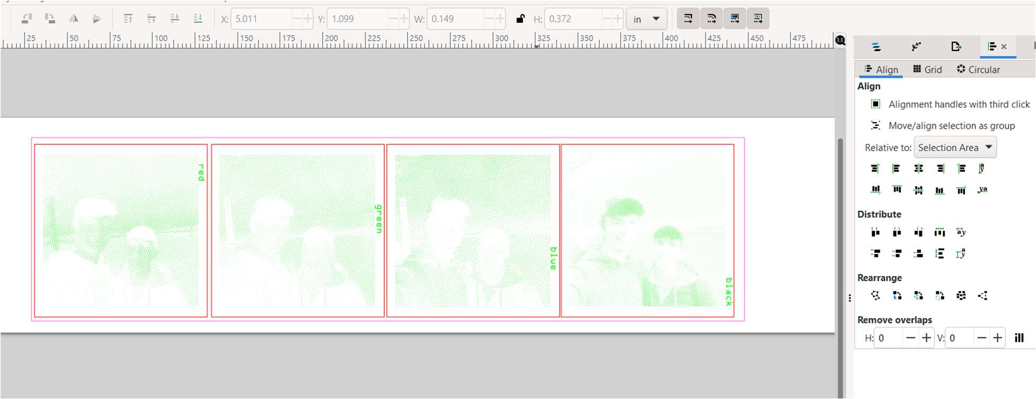
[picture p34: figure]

9

Lastly, we need to make cut lines to free our images from the acrylic. If you used the template, simply place your images in the 4 red squares, then center them using the “Align and Distribute” tool. Otherwise, make 4 red squares yourself using the rectangle tool. Make the dimensions 4” by 4” and then put them centered around your 4 color channels. Your final result should look similar to the image below.

Congratulations on making it this far! You’ve successfully created an advanced design for laser cutting and hopefully learned a ton while doing it. If you’re doing this for a workshop, you’re done as soon as you upload this file to the Lab64 website. Laser cutting is covered in the Stipple Holder assembly guide.

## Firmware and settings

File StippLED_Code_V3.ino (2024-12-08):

/*
Version 3.0
Developed for Lab64 Makerspace @ Stanford
Initial release 2024
Authors: Matthew Hamilton, Caleb Matthews, Ege Turan

Includes new animations and modes!
Mode 0 - Off
Mode 1 - RGB Display 
Mode 2 - Color Shift
Mode 3 - Noise flicker
*/

//NOTE: Check that pins A1 and A0 are the ones you selected for your project, if not edit lines 20 and 21 as necessary

#include <FastLED.h> // we’ll use the FastLED library

#define PPS 6 // Pixels Per Strip
#define NUM_STRIPS 3 // Establish number of strips (always 3 for the TSL project)
#define INTENSITY_PIN A1 //Establish Analog In A1 as volume
#define MODE_PIN A0   //Establish Analog In A0 as mode selector 

// Define the pins connected to the data lines of each LED strip
#define DATA_PIN_RED 1  // Red channel
#define DATA_PIN_GRN 2  // Green channel
#define DATA_PIN_BLU 3  // Blue channel

// Create CRGB array for all LED pixels
CRGB leds[PPS * NUM_STRIPS];

// Initialize integers for color shift (mode2)
int strip = 0;
int frame = 0;
int sign = 1;
int bound = 50;
int dividend = 0;

// Create the animation functions here with 3 cases
// Lights off Mode
void case0() {
  fill_solid(leds, PPS * NUM_STRIPS, CRGB::Black);
}

// RGB Mode - just display the R, G, B channels as normal. 
void case1(int intensity) {
  fill_solid(leds, 6, CHSV(0, 255, intensity));
  fill_solid(leds + 6, 6, CHSV(95, 255, intensity));
  fill_solid(leds + 12, 6, CHSV(160, 255, intensity));
}

// Color Shift Mode
void case2(int intensity) {
  frame = frame + sign;
  strip = dividend % 3;

  if (strip == 0) {
    fill_solid(leds, 6, CHSV(0 + frame, 255, intensity));
    fill_solid(leds + 6, 6, CHSV(95, 255, intensity));
    fill_solid(leds + 12, 6, CHSV(160, 255, intensity));
  }
  else if (strip == 1) {
    fill_solid(leds, 6, CHSV(0, 255, intensity));
    fill_solid(leds + 6, 6, CHSV(95 + frame, 255, intensity));
    fill_solid(leds + 12, 6, CHSV(160, 255, intensity));
  }
  else if (strip == 2) {
    fill_solid(leds, 6, CHSV(0, 255, intensity));
    fill_solid(leds + 6, 6, CHSV(95, 255, intensity));
    fill_solid(leds + 12, 6, CHSV(160 + frame, 255, intensity));
  }
  if (frame > 49) { //if the animation frame is at the top of its cycle i.e. frame = 50, switch the direction
    sign = sign * (-1);
  }
  else if (frame < 1) { //if the animation frame is at the end of its cycle i.e. frame = 0 and color is normal..
    sign = sign * (-1);
    dividend++; //increment the dividend 
    delay(1000);
  } 
  if (dividend > 32000) {
    dividend = 0;
  }
}

// Noise Mode
void case3(int intensity) {
  // Define base hues for each strip (Red, Green, Blue)
  uint8_t baseHue[3] = {0, 95, 160}; 

  for (int strip = 0; strip < NUM_STRIPS; strip++) {
    for (int pixel = 0; pixel < PPS; pixel++) {
      // Calculate the index of the current pixel
      int index = strip * PPS + pixel;

      // Randomly decide if this pixel should flicker
      bool flicker = random8() < 25;  // Adjust the probability here

      if (flicker) {
        // Dim the LED to 50% of the brightness
        leds[index] = CHSV(baseHue[strip], 255, intensity / 2);
      } else {
        // Set the pixel color with full intensity
        leds[index] = CHSV(baseHue[strip], 255, intensity);
      }
    }
  }
}



// Set up the LED array. This also plays an animation when connected to power.
void setup() {
  //Serial.begin(9600);
  pinMode(INTENSITY_PIN, INPUT);
  pinMode(MODE_PIN, INPUT);

  // Add LED strips with their respective data pins
  FastLED.addLeds<WS2812, DATA_PIN_RED>(leds, 0, 6);
  FastLED.addLeds<WS2812, DATA_PIN_GRN>(leds, 6, 12);
  FastLED.addLeds<WS2812, DATA_PIN_BLU>(leds, 12, 18);

  //Start-up Animation here
  //From black, fill all leds with white, then transition to RGB color
  fill_solid(leds, PPS * NUM_STRIPS, CRGB::Black);
  FastLED.show();
  delay(10);

  for (int hue = 0; hue < 255; hue++) {
    fill_solid(leds, PPS * NUM_STRIPS, CHSV(0, 0, hue));
    FastLED.show();
    delay(10);
  }
  delay(1000);
  fill_solid(leds, PPS * NUM_STRIPS, CRGB(175, 175, 175));
  FastLED.show();

  //Fade to the RGB scheme 
  for (int shift = 0; shift < 255; shift++) {
    fill_solid(leds, 6, CRGB(255, 255 - shift, 255 - shift));
    fill_solid(leds + 6, 6, CRGB(255 - shift, 255, 255 - shift));
    fill_solid(leds + 12, 6, CRGB(255 - shift, 255 - shift, 255));
    FastLED.show();
    delay(5);
  }
}

// Check the mode knob and the volume knob, then run through the corresponding display modes. 
void loop() {
  int volume = map(analogRead(INTENSITY_PIN), 0, 1024, 25, 255); //read the volume knob
  int mode = map(analogRead(MODE_PIN), 0, 1024, 0, 4);  //read the mode knob

  if (mode == 0) {
    case0();
    FastLED.show();
    delay(10);
  }
  
  else if (mode == 1) {
    case1(volume);
    FastLED.show();
    delay(10);
  }

  else if (mode == 2) {
    case2(volume);
    FastLED.show();
    delay(3);
  }

  else if (mode == 3) {
    case3(volume);
    FastLED.show();
    delay(25);
  }

  delay(25);
}

 
